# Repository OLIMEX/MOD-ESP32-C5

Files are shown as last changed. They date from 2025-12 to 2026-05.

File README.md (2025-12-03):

# MOD-ESP32-C5
ESP32-C5 dual band 2.4/5Ghz WiFi6 UEXT module

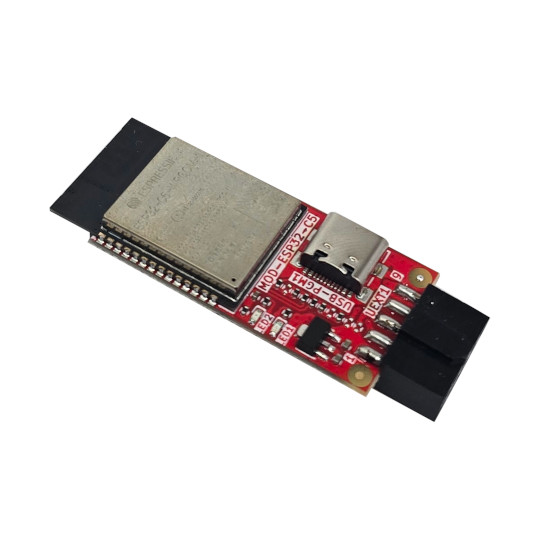
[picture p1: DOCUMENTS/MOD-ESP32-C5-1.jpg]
MOD-ESP32-C5-1


https://www.olimex.com/Products/IoT/ESP32-C5/MOD-ESP32-C5/open-source-hardware

## Licensee
* Hardware is released under CERN Open Hardware Licence Version 2 - Strongly Reciprocal
* Software is released under MIT Licensee
* Documentation is released under CC BY-SA 4.0

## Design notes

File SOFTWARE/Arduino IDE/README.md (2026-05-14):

# MOD-ESP32-C5 Arduino IDE Software

This directory contains the Arduino IDE library, MOD-ESP32-C5 firmware example,
host board demos, and Linux userspace demos for using MOD-ESP32-C5 as a WiFi
modem over UEXT/UART.

## Directory Layout

```text
Arduino IDE/
  README.md
  OlimexWiFiModem.zip
  OlimexWiFiModem/
    library.properties
    README.md
    src/
    examples/
      ESP32_C5_Firmware/
      BasicDemo/
      WebServerDemo/
  Linux/
    README.md
    requirements.txt
    olimex_wifi_modem.py
    basic_demo.py
    web_server_demo.py
```

## Arduino IDE Library

Use `OlimexWiFiModem.zip` for the normal Arduino IDE install flow:

1. Open Arduino IDE.
2. Select `Sketch -> Include Library -> Add .ZIP Library...`.
3. Select `OlimexWiFiModem.zip`.
4. Open examples from `File -> Examples -> OlimexWiFiModem`.

The unzipped `OlimexWiFiModem/` folder is included for source browsing,
development, and GitHub visibility. Its internal structure is the standard
Arduino library layout.

Important examples:

- `ESP32_C5_Firmware` - upload this to MOD-ESP32-C5.
- `BasicDemo` - upload this to an Arduino-compatible host board to test WiFi.
- `WebServerDemo` - upload this to a host board to serve a browser LED button.

Read [OlimexWiFiModem/README.md](OlimexWiFiModem/README.md) for the full
Arduino setup guide.

## Linux Examples

The `Linux/` folder contains Python examples for OLinuXino boards and other
Linux hosts connected to MOD-ESP32-C5 over UEXT/UART.

The MOD-ESP32-C5 must already be flashed with the Arduino
`ESP32_C5_Firmware` example before using the Linux scripts.

Read [Linux/README.md](Linux/README.md) for Linux installation and usage.

## Tested Notes

- OLIMEXINO-2560 host examples use `Serial1` for UEXT.
- A20-OLinuXino-MICRO UEXT1 was tested as `/dev/ttyS4`.
- A20-OLinuXino-MICRO LED1 is controlled through `/sys/class/leds`.
- UART speed is `115200 baud`.

For other boards, adjust the host serial port or Linux `/dev/ttySx` device to
match the board schematic and image.

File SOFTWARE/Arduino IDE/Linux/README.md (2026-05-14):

# OLinuXino Example For MOD-ESP32-C5

Linux userspace examples for using MOD-ESP32-C5 from an OLinuXino board.

The MOD-ESP32-C5 firmware is assumed to be already flashed with the Arduino
`ESP32_C5_Firmware` example. These files only run on the Linux host board.

## Files

```text
Linux/
  README.md
  requirements.txt
  olimex_wifi_modem.py
  basic_demo.py
  web_server_demo.py
```

- `olimex_wifi_modem.py` - Python driver for the MOD-ESP32-C5 UART protocol.
- `basic_demo.py` - checks the modem, connects WiFi, and prints the IP address.
- `web_server_demo.py` - serves a browser button through MOD-ESP32-C5.

## Install Dependency

On Debian-based OLinuXino images:

```sh
apt update
apt install python3 python3-serial
```

## Download Directly On The Board

```sh
mkdir -p MOD-ESP32-C5-Linux
cd MOD-ESP32-C5-Linux

wget -O basic_demo.py https://github.com/OLIMEX/MOD-ESP32-C5/raw/refs/heads/main/SOFTWARE/Arduino%20IDE/Linux/basic_demo.py
wget -O olimex_wifi_modem.py https://github.com/OLIMEX/MOD-ESP32-C5/raw/refs/heads/main/SOFTWARE/Arduino%20IDE/Linux/olimex_wifi_modem.py
wget -O web_server_demo.py https://github.com/OLIMEX/MOD-ESP32-C5/raw/refs/heads/main/SOFTWARE/Arduino%20IDE/Linux/web_server_demo.py
```

## Serial Port

For A20-OLinuXino-MICRO with MOD-ESP32-C5 connected to UEXT1, the schematic
shows A20 UART6 on UEXT1. On the tested Linux image this appears as:

```text
/dev/ttyS4
```

The examples default to `/dev/ttyS4`.

For another OLinuXino board, another UEXT connector, or another Linux image,
change `--port /dev/ttyS4` to the correct `/dev/ttySx`.

Useful checks:

```sh
ls -l /dev/ttyS*
dmesg | grep tty
```

## Basic Demo

```sh
python3 basic_demo.py --port /dev/ttyS4 --ssid WIFI_SSID --password WIFI_PASSWORD
```

Expected output:

```text
================================
MOD-ESP32-C5 Linux Basic Demo
================================
Serial port: /dev/ttyS4
Checking modem...
[TX] ping
[RX] PONG
Modem OK
Connecting to WiFi...
[TX] connect MyRouter MyPassword
[RX] WIFI:CONNECTED
[TX] ip
[RX] IP:192.168.0.198
WiFi connected, IP: 192.168.0.198
```

## Web Server Demo

```sh
python3 web_server_demo.py --port /dev/ttyS4 --ssid WIFI_SSID --password WIFI_PASSWORD
```

Open the printed IP address in a browser on the same network.

Expected result:

- Page title: `OLinuXino + MOD-ESP32-C5`
- Button toggles LED1 on A20-OLinuXino-MICRO.
- Browser refreshes and stale connections are handled without stopping the script.

On A20-OLinuXino-MICRO, LED1 is exposed by the kernel LED subsystem. The web
demo selects a likely LED automatically. To choose one explicitly:

```sh
ls -l /sys/class/leds
python3 web_server_demo.py --port /dev/ttyS4 --ssid WIFI_SSID --password WIFI_PASSWORD --led LED_NAME
```

To run the web demo without controlling a physical LED:

```sh
python3 web_server_demo.py --port /dev/ttyS4 --ssid WIFI_SSID --password WIFI_PASSWORD --no-led
```

## Notes

- Run as `root` if your Linux image restricts serial or LED access.
- If the log shows `DATA:0`, `ERROR:BAD_ID`, or `ERROR:CLOSED` during browser
  refreshes, this usually means the browser opened or closed an extra socket.
  The latest scripts treat this as normal and keep running.
- If the log shows split protocol text such as `S` followed by
  `ERVER:CLIENT:3`, update `olimex_wifi_modem.py`; the driver reassembles known
  fragmented protocol lines.

## Protocol Summary

The Linux scripts send newline-terminated text commands over UEXT UART:

```text
ping
connect <ssid> <password>
ip
server start <port>
server read <client_id>
server write <client_id> <byte_count>
server close <client_id>
```

Common firmware replies:

```text
PONG
WIFI:CONNECTED
IP:192.168.0.198
SERVER:STARTED
SERVER:CLIENT:0
DATA:304
READY
OK
ERROR:...
```

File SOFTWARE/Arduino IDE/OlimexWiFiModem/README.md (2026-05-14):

# OlimexWiFiModem

Arduino IDE library and examples for using MOD-ESP32-C5 as a WiFi modem over
UEXT/UART.

The main target setup is:

- Main board: OLIMEXINO-2560
- WiFi modem board: MOD-ESP32-C5
- Link between boards: UEXT UART at 115200 baud

The firmware can also be used with other host boards that can talk over a UART,
for example other Arduino-compatible boards or OLIMEX Linux boards connected to
UEXT. The host side must send the same text commands described below.

## What Is In This Folder

```text
OlimexWiFiModem/
  library.properties
  README.md
  src/
    OlimexWiFiModem.h
    OlimexWiFiModem.cpp
  examples/
    ESP32_C5_Firmware/
      ESP32_C5_Firmware.ino
    BasicDemo/
      BasicDemo.ino
    WebServerDemo/
      WebServerDemo.ino
```

`ESP32_C5_Firmware` is uploaded to MOD-ESP32-C5.

`BasicDemo` and `WebServerDemo` are uploaded to the host board, for example
OLIMEXINO-2560.

## Install In Arduino IDE From ZIP

This folder is meant to be zipped and installed directly in Arduino IDE.

1. Zip the whole `OlimexWiFiModem` folder.
2. Open Arduino IDE.
3. Select `Sketch -> Include Library -> Add .ZIP Library...`.
4. Select the ZIP file.
5. Open the examples from `File -> Examples -> OlimexWiFiModem`.

After installation, Arduino IDE should show these examples:

- `ESP32_C5_Firmware`
- `BasicDemo`
- `WebServerDemo`

## Hardware Setup

1. Connect MOD-ESP32-C5 to the host board through UEXT.
2. Power the boards as recommended for your hardware.
3. Use a USB cable for the board you are programming.
4. Open Serial Monitor at `115200 baud`.

For OLIMEXINO-2560, the examples use:

```cpp
HardwareSerial &ModemSerial = Serial1;
```

This means the library talks to MOD-ESP32-C5 through `Serial1`.

For another host board, change this line to the hardware serial port connected
to the UEXT UART.

## Step 1: Upload The MOD-ESP32-C5 Firmware

Open:

`File -> Examples -> OlimexWiFiModem -> ESP32_C5_Firmware`

Select the correct ESP32-C5 board and port in Arduino IDE, then upload.

After reset, open Serial Monitor at `115200 baud`. Expected output:

```text
READY
>
```

This means the firmware is running and waiting for commands from the host board.

## Step 2: Run BasicDemo On The Host Board

Open:

`File -> Examples -> OlimexWiFiModem -> BasicDemo`

Before uploading, edit these two lines:

```cpp
#define WIFI_SSID "WIFI_SSID"
#define WIFI_PASSWORD "WIFI_PASSWORD"
```

Example:

```cpp
#define WIFI_SSID "MyRouter"
#define WIFI_PASSWORD "MyPassword"
```

Upload the sketch to OLIMEXINO-2560 or another host board.

Open Serial Monitor at `115200 baud`. Expected output will look similar to:

```text
================================
OlimexWiFiModem Basic Demo
================================
Checking MOD-ESP32-C5...
[TX] ping
[RX] PONG
Modem OK
Connecting to WiFi...
[TX] connect MyRouter MyPassword
[RX] WIFI:CONNECTED
WiFi connected
[TX] ip
[RX] IP:192.168.0.198
IP: 192.168.0.198
Basic demo finished.
```

Your IP address will probably be different.

## Step 3: Run WebServerDemo On The Host Board

Open:

`File -> Examples -> OlimexWiFiModem -> WebServerDemo`

Before uploading, edit these two lines:

```cpp
#define WIFI_SSID "WIFI_SSID"
#define WIFI_PASSWORD "WIFI_PASSWORD"
```

Upload the sketch and open Serial Monitor at `115200 baud`.

Expected startup output:

```text
================================
OLIMEXINO-2560 Web Server Demo
================================
[TX] ping
[RX] PONG
Modem OK
Connecting to WiFi...
[TX] connect MyRouter MyPassword
[RX] WIFI:CONNECTED
WiFi connected
[TX] ip
[RX] IP:192.168.0.198
Module IP: 192.168.0.198
[TX] server start 80
[RX] SERVER:STARTED
HTTP server started
Open browser: http://192.168.0.198
```

Open the printed address in a browser connected to the same network.

Expected result:

- A web page opens with title `OLIMEXINO-2560`.
- The page shows `LED is OFF` or `LED is ON`.
- Pressing `Toggle LED` changes the board LED on pin 13.
- The page updates quickly without a full page reload.

When the browser connects, Serial Monitor will show request/response activity:

```text
[RX] SERVER:CLIENT:0
Client connected, ID=0
[TX] server read 0
[RX] DATA:304
Request: GET /toggle HTTP/1.1
LED state changed to: ON
[TX] server write 0 91
[RX] READY
[RX] OK
[TX] server close 0
[RX] OK
Client closed
```

The exact byte counts can be different.

## How The Firmware And Library Communicate

The host board sends text commands to MOD-ESP32-C5 over UART. Each command ends
with a newline.

Common commands:

```text
ping
connect <ssid> <password>
ip
server start <port>
server read <client_id>
server write <client_id> <byte_count>
server close <client_id>
```

Common firmware replies:

```text
PONG
WIFI:CONNECTED
IP:192.168.0.198
SERVER:STARTED
SERVER:CLIENT:0
DATA:304
READY
OK
ERROR:...
```

For HTTP server use, MOD-ESP32-C5 accepts the browser connection and notifies
the host board with `SERVER:CLIENT:<id>`. The host board then reads the browser
request, writes an HTTP response, and closes the browser client.

## Troubleshooting

If Serial Monitor shows `Modem not found`:

- Check that MOD-ESP32-C5 is flashed with `ESP32_C5_Firmware`.
- Check UEXT connection and board power.
- Check that the host sketch uses the correct serial port.
- Make sure both sides use `115200 baud`.

If Serial Monitor shows `WiFi failed`:

- Check the SSID and password.
- Make sure the WiFi network is in range.
- Use a 2.4 GHz network if your ESP32-C5 setup does not support the selected
  router mode.

If the web page does not open:

- Confirm that `HTTP server started` is printed.
- Confirm that your computer or phone is on the same network.
- Open the exact IP address printed by the Serial Monitor.
- Try refreshing the browser after the board prints a new IP address.

If the button is slow or stops responding:

- Reflash MOD-ESP32-C5 with the firmware from this library.
- Reupload the latest `WebServerDemo`.
- Watch Serial Monitor for `ERROR:` messages.

## Using Other Host Boards

The library is written for Arduino-style `Stream` objects. This means the host
board only needs a serial port connected to the MOD-ESP32-C5 UEXT UART.

For boards such as OLIMEXINO-328, the serial port may be different from
OLIMEXINO-2560. Update this line in the demos:

```cpp
HardwareSerial &ModemSerial = Serial1;
```

Use the serial object that matches your wiring.

For Linux boards, the same protocol can be used from a userspace program that
opens the UEXT serial device at `115200 baud` and sends the text commands shown
above.

## Notes For Beginners

- Upload `ESP32_C5_Firmware` to MOD-ESP32-C5 first.
- Upload `BasicDemo` or `WebServerDemo` to the main board second.
- Always edit `WIFI_SSID` and `WIFI_PASSWORD` before uploading host demos.
- Keep Serial Monitor open at `115200 baud`; it is the easiest way to see what
  is happening.
- The IP address is assigned by your router, so it may change between tests.

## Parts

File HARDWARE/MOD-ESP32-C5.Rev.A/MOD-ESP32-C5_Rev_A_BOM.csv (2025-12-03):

Quantity | Value | Footprint | Reference
1 | 1uF/6.3V/10%/X5R/C0402 | C_0402_5MIL_DWS | C3
2 | 10uF/6.3V/20%/X5R/C0402 | C_0402_5MIL_DWS | C6, C7
1 | LED/Green/0603 | LED_0603_KA | LED1
1 | LED/Red/0603 | LED_0603_KA | LED2
2 | 5.1k/1%/R0402 | R_0402_5MIL_DWS | R1, R2
1 | 10k/R0402 | R_0402_5MIL_DWS | R3
2 | 33R/R0402 | R_0402_5MIL_DWS | R4, R5
2 | 2.2k/R0402 | R_0402_5MIL_DWS | R6, R7
2 | GG0402052R542P | D_0402_5MIL_DWS | TVS1, TVS2
1 | ESP32-C5-WROOM-1-N8R4 | ESP32-C5-WROOM-1-N**4-UNIVERSAL_MODULE | U1
1 | FK-DK-2X05-LF(IDC-10S_PCB) | FK-DK-2X05-LF(IDC-10S_PCB)-SMD | UEXT1
1 | USB-C-16P-F(A40-00119-A52-12) | USB2.0_TYPE-C(A40-00119-A52-12)_Paste | USB-PGM1
1 | WL9005P3-33(SOT89-3) | SOT89-3 | VR1

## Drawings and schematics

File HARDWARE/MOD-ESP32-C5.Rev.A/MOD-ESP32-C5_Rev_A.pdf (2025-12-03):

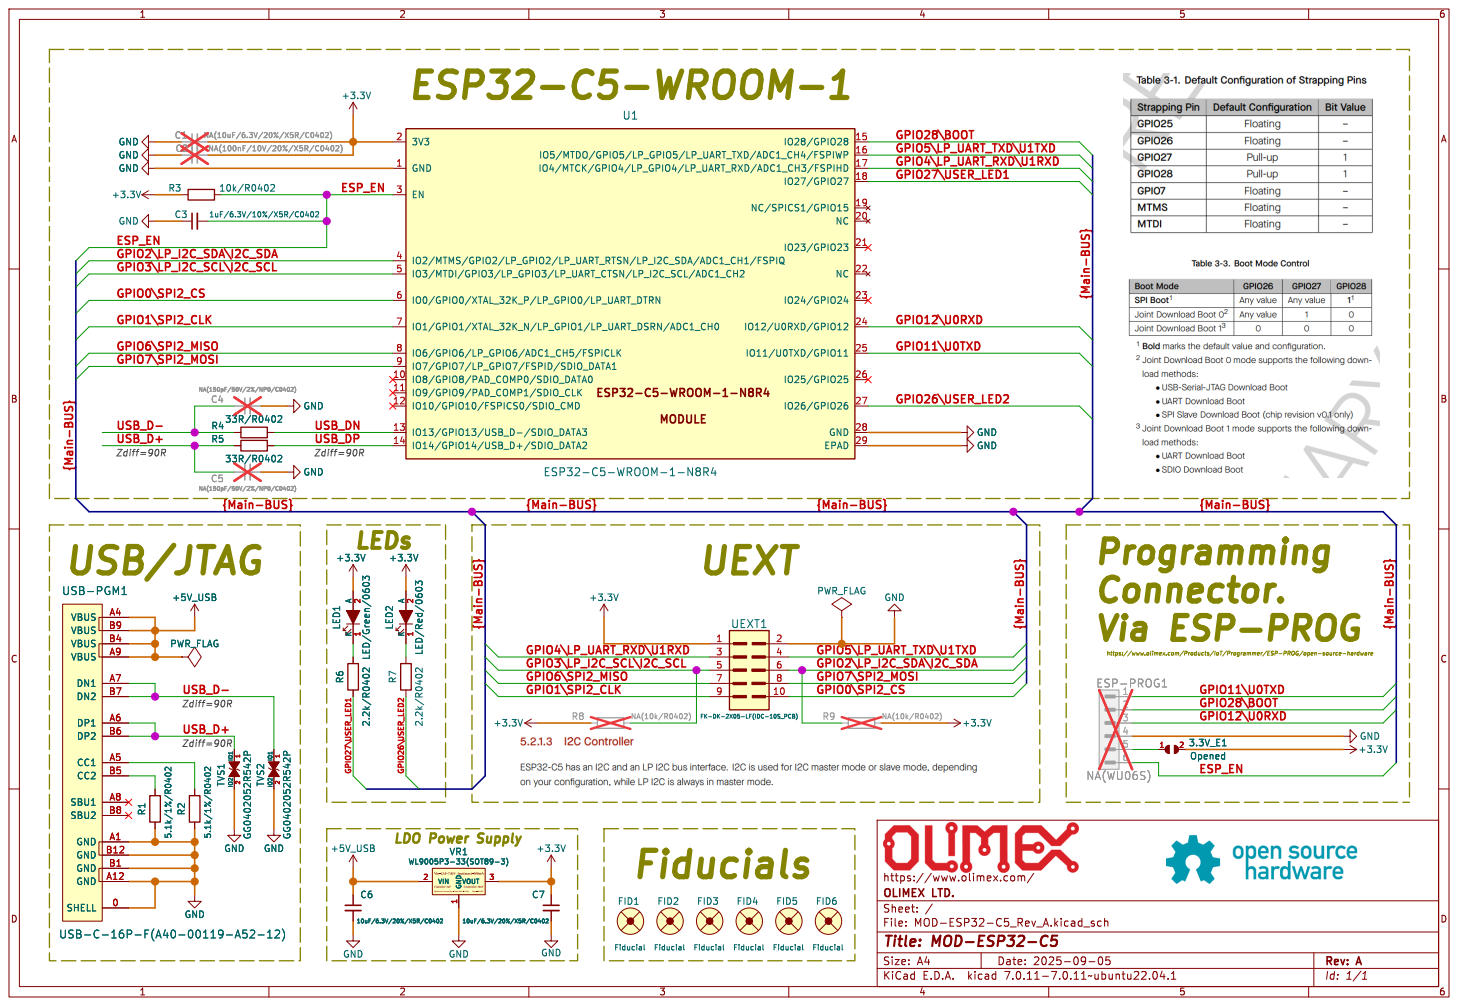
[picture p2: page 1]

Via ESP-PROG https://www.olimex.com/Products/IoT/Programmer/ESP-PROG/open-source-hardware Fiducials

FK-DK-2X05-LF(IDC-10S_PCB)

QuiescentCurrent(Typ=0.3uA;Max=0.7uA) Topr=-40~85C Vin=(2.0~7.0)V GND

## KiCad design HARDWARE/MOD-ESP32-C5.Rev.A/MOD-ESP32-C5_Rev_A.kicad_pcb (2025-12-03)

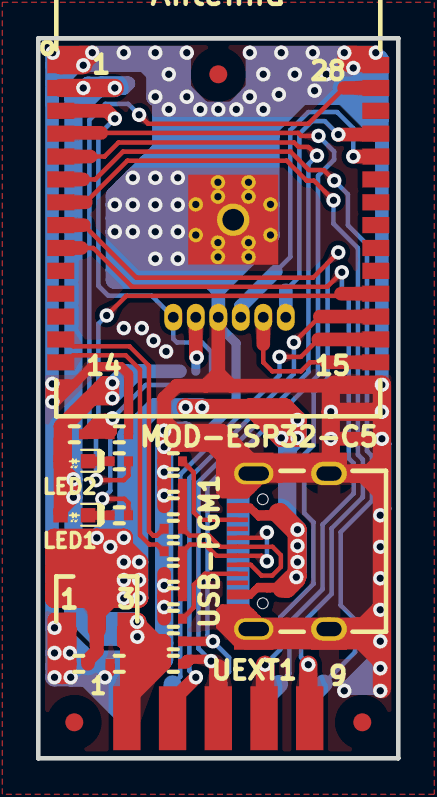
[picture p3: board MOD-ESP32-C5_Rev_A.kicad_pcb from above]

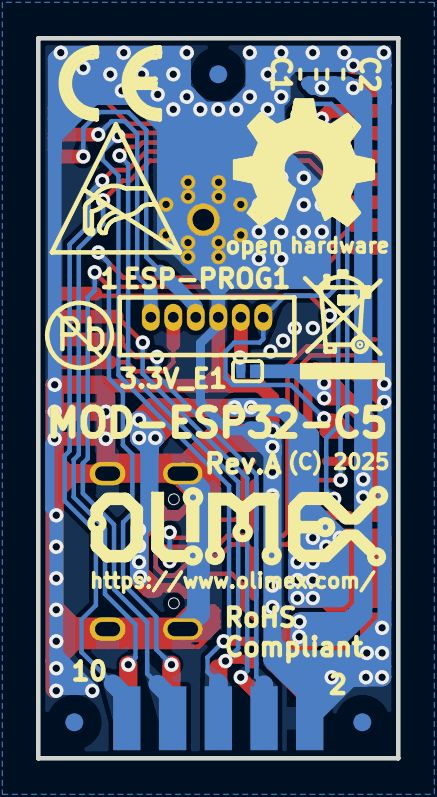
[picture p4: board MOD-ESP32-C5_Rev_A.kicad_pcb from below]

Board: 2 copper layers, 20.0 x 40.0 mm, 38 parts (13 on the bottom side), 26 nets.

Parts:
3.3V_E1: Opened; SJ_1_SMALLER
C1: NA(10uF/6.3V/20%/X5R/C0402); C_0402_5MIL_DWS
C2: NA(100nF/10V/20%/X5R/C0402); C_0402_5MIL_DWS
C3: 1uF/6.3V/10%/X5R/C0402; C_0402_5MIL_DWS
C4, C5: NA(150pF/50V/2%/NP0/C0402); C_0402_5MIL_DWS
C6, C7: 10uF/6.3V/20%/X5R/C0402; C_0402_5MIL_DWS
ESP-PROG1: NA(WU06S); WU06S
FID1, FID2, FID5, FID6: Fiducial; Fiducial1x3
FID3, FID4: Fiducial; Fiducial1x3_Paste
LED1: LED/Green/0603; LED_0603_KA
LED2: LED/Red/0603; LED_0603_KA
Logo_OLIMEX_TB: Logo_OLIMEX_TB
R1, R2: 5.1k/1%/R0402; R_0402_5MIL_DWS
R3: 10k/R0402; R_0402_5MIL_DWS
R4, R5: 33R/R0402; R_0402_5MIL_DWS
R6, R7: 2.2k/R0402; R_0402_5MIL_DWS
R8, R9: NA(10k/R0402); R_0402_5MIL_DWS
Sign_Antistatic: Sign_Antistatic
Sign_CE: CE_Sign
Sign_OSHW_8x8: Sign_OSHW_8x8
Sign_PB-Free: Sign_PB-Free
Sign_RecycleBin_1: Sign_RecycleBin_1
TVS1, TVS2: GG0402052R542P; D_0402_5MIL_DWS
U1: ESP32-C5-WROOM-1-N8R4; ESP32-C5-WROOM-1-N**4-UNIVERSAL_MODULE
UEXT1: FK-DK-2X05-LF(IDC-10S_PCB); FK-DK-2X05-LF(IDC-10S_PCB)-SMD
USB-PGM1: USB-C-16P-F(A40-00119-A52-12); USB2.0_TYPE-C(A40-00119-A52-12)_Paste
VR1: WL9005P3-33(SOT89-3); SOT89-3

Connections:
+3.3V: 3.3V_E1.2, C1.2, C2.1, C7.1, LED1.2 (A), LED2.2 (A), R3.2, R8.1, R9.2, U1.2 (3V3), UEXT1.1, VR1.3 (VOUT)
+5V_USB: C6.1, USB-PGM1.A4 (VBUS), USB-PGM1.A9 (VBUS), USB-PGM1.B4 (VBUS), USB-PGM1.B9 (VBUS), VR1.2 (VIN)
/ESP_EN: C3.2, ESP-PROG1.6, R3.1, U1.3 (EN)
/GPIO0\SPI2_CS: U1.6 (IO0/GPIO0/XTAL_32K_P/LP_GPIO0/LP_UART_D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), UEXT1.10
/GPIO1\SPI2_CLK: U1.7 (IO1/GPIO1/XTAL_32K_N/LP_GPIO1/LP_UART_D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), UEXT1.9
/GPIO2\LP_I2C_SDA\I2C_SDA: R9.1, U1.4 (IO2/MTMS/GPIO2/LP_GPIO2/LP_UART_RTSN/LP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), UEXT1.6
/GPIO3\LP_I2C_SCL\I2C_SCL: R8.2, U1.5 (IO3/MTDI/GPIO3/LP_GPIO3/LP_UART_CTSN/LP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), UEXT1.5
/GPIO4\LP_UART_RXD\U1RXD: U1.17 (IO4/MTCK/GPIO4/LP_GPIO4/LP_UART_RXD/ADC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), UEXT1.3
/GPIO5\LP_UART_TXD\U1TXD: U1.16 (IO5/MTDO/GPIO5/LP_GPIO5/LP_UART_TXD/ADC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), UEXT1.4
/GPIO6\SPI2_MISO: U1.8 (IO6/GPIO6/LP_GPIO6/ADC1_CH5/FSPICLK), UEXT1.7
/GPIO7\SPI2_MOSI: U1.9 (IO7/GPIO7/LP_GPIO7/FSPID/SDIO_DATA1), UEXT1.8
/GPIO11\U0TXD: ESP-PROG1.1, U1.25 (IO11/U0TXD/GPIO11)
/GPIO12\U0RXD: ESP-PROG1.3, U1.24 (IO12/U0RXD/GPIO12)
/GPIO26\USER_LED2: R7.2, U1.27 (IO26/GPIO26)
/GPIO27\USER_LED1: R6.2, U1.18 (IO27/GPIO27)
/GPIO28\BOOT: ESP-PROG1.2, U1.15 (IO28/GPIO28)
/USB_D+: C5.1, R5.2, TVS1.1 (IO1), USB-PGM1.A6 (DP1), USB-PGM1.B6 (DP2)
/USB_D-: C4.1, R4.1, TVS2.1 (IO1), USB-PGM1.A7 (DN1), USB-PGM1.B7 (DN2)
/USB_DN: R4.2, U1.13 (IO13/GPIO13/USB_D-/SDIO_DATA3)
/USB_DP: R5.1, U1.14 (IO14/GPIO14/USB_D+/SDIO_DATA2)
GND: C1.1, C2.2, C3.1, C4.2, C5.2, C6.2, C7.2, ESP-PROG1.4, R1.1, R2.1, TVS1.2 (IO2), TVS2.2 (IO2), U1.1 (GND), U1.28 (GND), U1.29 (EPAD), UEXT1.2, USB-PGM1.0 (SHELL), USB-PGM1.A1 (GND), USB-PGM1.A12 (GND), USB-PGM1.B1 (GND), USB-PGM1.B12 (GND), VR1.1 (GND)
unnamed: 3.3V_E1.1, ESP-PROG1.5
unnamed: LED1.1 (K), R6.1
unnamed: LED2.1 (K), R7.1
unnamed: R2.2, USB-PGM1.A5 (CC1)
unnamed: R1.2, USB-PGM1.B5 (CC2)

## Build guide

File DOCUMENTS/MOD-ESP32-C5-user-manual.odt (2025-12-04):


MOD-ESP32-C5

User Manual

Rev.1.0 November 2025 olimex.com

# What is MOD-ESP32-C5

MOD- (https://www.olimex.com/Products/IoT/ESP32-C5/MOD-ESP32-C5/open-source-hardware)ESP32-C5 (https://www.olimex.com/Products/IoT/ESP32-C5/MOD-ESP32-C5/open-source-hardware) is Dual band 2.4Ghz and 5Ghz WiFi 6, Bluetooth 5 LE, Zigbee, Thread, Matter development board with UEXTconnector.

The board is with ESP32-C5-WROOM-N8R4 module with 8MB of Flash and 4MB of RAM

The features of MOD- (https://www.olimex.com/Products/IoT/ESP32-C5/MOD-ESP32-C5/open-source-hardware)ESP32-C5 (https://www.olimex.com/Products/IoT/ESP32-C5/MOD-ESP32-C5/open-source-hardware) are:

- ESP32-C5-WROOM-N8R4 module
- 32 bit RISC-V processor 240Mhz
- Dual-Band Wi-Fi (2.4 GHz + 5 GHz)
- Bluetooth 5, Zigbee, Thread, Matter
- 8 MB Flash + 4 MB RAM
- UEXT connector
- USB-C JTAG
- Two status LEDs
- Dimensions 40x20mm
  MOD- (https://www.olimex.com/Products/IoT/ESP32-C5/MOD-ESP32-C5/open-source-hardware)ESP32-C5 (https://www.olimex.com/Products/IoT/ESP32-C5/MOD-ESP32-C5/open-source-hardware) is Open Source Hardware, all CAD files and firmware and available, so people can study and modify.

## Order codes for MOD-ESP32-C5 and accessories:

MOD- (https://www.olimex.com/Products/IoT/ESP32-C5/MOD-ESP32-C5/open-source-hardware)ESP32-C5 (https://www.olimex.com/Products/IoT/ESP32-C5/MOD-ESP32-C5/open-source-hardware) ESP32-C5 development board

USB-CABLE-AM-USB3-C (https://www.olimex.com/Products/Components/Cables/USB-CABLE-AM-USB3-C/) High speed, High current cable for power supply and programming

# HARDWARE

## MOD-ESP32-C5 layout:

## UEXT connector:

MOD- (https://www.olimex.com/Products/IoT/ESP32-C5/MOD-ESP32-C5/open-source-hardware)ESP32-C5 (https://www.olimex.com/Products/IoT/ESP32-C5/MOD-ESP32-C5/open-source-hardware) has UEXT connector which is compatible with the UEXT connector on all our other development boards.

Note that UEXT connector have UART which signals have to be crossed. So there is UEXT HOST and UEXT device connectors.

The UEXT HOST connector is male connector with pins. The UEXT DEVICE connector is with receptacle connector.

Our development boards with UEXT have UEXT HOST connector.

MOD- (https://www.olimex.com/Products/IoT/ESP32-C5/MOD-ESP32-C5/open-source-hardware)ESP32-C5 (https://www.olimex.com/Products/IoT/ESP32-C5/MOD-ESP32-C5/open-source-hardware) is with UEXT DEVICE connector.

UEXT connector can be in different shapes.

The original UEXT connector is 0.1” 2.54mm step boxed plastic connector. All signals are with 3.3V levels. Here is picture of UEXT HOST connector (with pins):

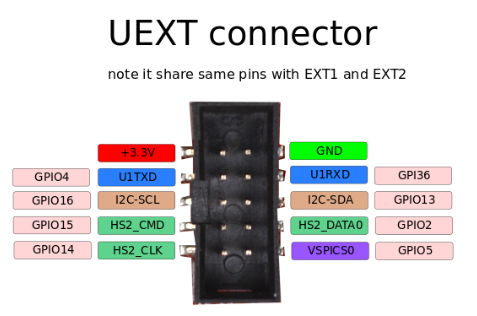
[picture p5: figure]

## MOD-ESP32-C5 UEXT connector wiring:

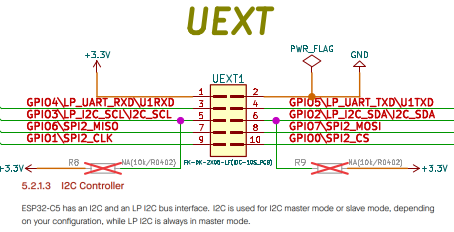
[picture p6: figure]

## LEDs:

MOD- (https://www.olimex.com/Products/IoT/ESP32-C5/MOD-ESP32-C5/open-source-hardware)ESP32-C5 (https://www.olimex.com/Products/IoT/ESP32-C5/MOD-ESP32-C5/open-source-hardware) has two status LEDs

LED1 is Green and connected to GPIO27

LED2 is Red and connected to GPIO26

## MOD-ESP32-C5 schematics:

MOD- (https://www.olimex.com/Products/IoT/ESP32-C5/MOD-ESP32-C5/open-source-hardware)ESP32-C5 (https://www.olimex.com/Products/IoT/ESP32-C5/MOD-ESP32-C5/open-source-hardware) latest schematic is on GitHub (https://github.com/OLIMEX/MOD-ESP32-C5/blob/main/HARDWARE/MOD-ESP32-C5.Rev.A/MOD-ESP32-C5_Rev_A.pdf)

# SOFTWARE:

ESP32-C5- (https://www.olimex.com/Products/IoT/ESP32-C5/ESP32-C5-DevKit-Lipo/open-source-hardware)DevKit-Lipo (https://www.olimex.com/Products/IoT/ESP32-C5/ESP32-C5-DevKit-Lipo/open-source-hardware) can be programmed with Espressif IDF 5.5 and Arduino.

# Revision History

Revision 1.0 November 2025

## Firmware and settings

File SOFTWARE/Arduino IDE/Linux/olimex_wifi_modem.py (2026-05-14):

#!/usr/bin/env python3
"""Linux driver for MOD-ESP32-C5 running the Olimex WiFi modem firmware."""

import time

import serial


class OlimexWiFiModem:
    def __init__(self, port="/dev/ttyS4", baudrate=115200, debug=True):
        self.ser = serial.Serial(port=port, baudrate=baudrate, timeout=0.05)
        self.debug = debug
        self.pending_clients = []
        self.line_fragment = ""

    def close(self):
        self.ser.close()

    def flush_input(self):
        self.ser.reset_input_buffer()

    def send_cmd(self, cmd):
        if self.debug:
            print(f"[TX] {cmd}")
        self.ser.write((cmd + "\n").encode("utf-8"))
        self.ser.flush()

    def normalize_line(self, line):
        known = (
            "PONG",
            "WIFI:CONNECTED",
            "IP:",
            "SERVER:STARTED",
            "SERVER:CLIENT:",
            "DATA:",
            "READY",
            "OK",
            "END",
            "ERROR:",
        )

        if self.line_fragment:
            line = self.line_fragment + line
            self.line_fragment = ""

        if line in ("WIFI:", "IP:", "DATA:", "SERVER:CLIENT:", "ERROR:"):
            self.line_fragment = line
            return ""

        if any(prefix.startswith(line) and prefix != line for prefix in known):
            self.line_fragment = line
            return ""

        return line

    def read_line(self, timeout=2.0):
        end = time.monotonic() + timeout
        data = bytearray()

        while time.monotonic() < end:
            b = self.ser.read(1)
            if not b:
                continue

            ch = b[0]
            if ch == ord("\r"):
                continue

            if ch == ord("\n"):
                line = data.decode("utf-8", errors="replace").strip()
                if line.startswith(">"):
                    line = line[1:].strip()
                if line:
                    return self.normalize_line(line)
                data.clear()
                continue

            if ch == ord(">") and not data:
                continue

            data.append(ch)

        line = data.decode("utf-8", errors="replace").strip()
        if line.startswith(">"):
            line = line[1:].strip()
        if line:
            return self.normalize_line(line)
        return line

    def read_exact(self, size, timeout=2.0):
        end = time.monotonic() + timeout
        data = bytearray()

        while len(data) < size and time.monotonic() < end:
            chunk = self.ser.read(size - len(data))
            if chunk:
                data.extend(chunk)

        if len(data) != size:
            raise TimeoutError(f"Expected {size} bytes, received {len(data)}")

        return bytes(data)

    def cache_client_line(self, line):
        if line.startswith("SERVER:CLIENT:"):
            self.pending_clients.append(int(line.split(":", 2)[2]))
            return True
        return False

    def wait_for(self, token, timeout=3.0):
        end = time.monotonic() + timeout
        recent = ""

        while time.monotonic() < end:
            line = self.read_line(timeout=0.2)
            if not line:
                continue

            if self.debug:
                print(f"[RX] {line}")

            self.cache_client_line(line)

            if line.startswith("ERROR:"):
                return False

            recent = (recent + line)[-128:]

            if token in line or token in recent:
                return True

        return False

    def begin(self):
        self.flush_input()
        self.send_cmd("ping")
        return self.wait_for("PONG", timeout=3.0)

    def connect_wifi(self, ssid, password):
        self.flush_input()
        self.send_cmd(f"connect {ssid} {password}")
        return self.wait_for("WIFI:CONNECTED", timeout=15.0)

    def ip(self):
        self.flush_input()
        self.send_cmd("ip")

        end = time.monotonic() + 3.0
        while time.monotonic() < end:
            line = self.read_line(timeout=0.5)
            if not line:
                continue

            if self.debug:
                print(f"[RX] {line}")

            self.cache_client_line(line)

            if line.startswith("IP:"):
                return line[3:]

        return ""

    def server_start(self, port=80):
        self.flush_input()
        self.send_cmd(f"server start {port}")
        return self.wait_for("SERVER:STARTED", timeout=3.0)

    def server_available(self):
        if self.pending_clients:
            return self.pending_clients.pop(0)

        line = self.read_line(timeout=0.05)
        if not line:
            return -1

        if self.debug:
            print(f"[RX] {line}")

        if line.startswith("SERVER:CLIENT:"):
            return int(line.split(":", 2)[2])

        return -1

    def server_read(self, client_id, timeout=2.0):
        self.send_cmd(f"server read {client_id}")
        end = time.monotonic() + timeout

        while time.monotonic() < end:
            line = self.read_line(timeout=0.2)
            if not line:
                continue

            if self.debug:
                print(f"[RX] {line}")

            if line in ("ERROR:BAD_ID", "ERROR:CLOSED"):
                return None

            if line.startswith("ERROR:"):
                raise RuntimeError(line)

            if self.cache_client_line(line):
                continue

            if not line.startswith("DATA:"):
                continue

            size = int(line[5:])
            payload = self.read_exact(size, timeout=timeout)

            trailer_end = time.monotonic() + 0.5
            while time.monotonic() < trailer_end:
                trailer = self.read_line(timeout=0.1)
                if trailer == "END":
                    break
                if trailer:
                    if self.debug:
                        print(f"[RX] {trailer}")
                    self.cache_client_line(trailer)

            return payload

        raise TimeoutError("Timed out waiting for DATA")

    def server_write(self, client_id, data):
        if isinstance(data, str):
            data = data.encode("utf-8")

        self.send_cmd(f"server write {client_id} {len(data)}")

        if not self.wait_for("READY", timeout=3.0):
            return False

        self.ser.write(data)
        self.ser.flush()

        return self.wait_for("OK", timeout=3.0)

    def server_close(self, client_id):
        self.send_cmd(f"server close {client_id}")
        return self.wait_for("OK", timeout=3.0)

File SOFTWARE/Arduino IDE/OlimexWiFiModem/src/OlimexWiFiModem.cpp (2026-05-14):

#include "OlimexWiFiModem.h"

OlimexWiFiModem::OlimexWiFiModem(
  Stream &serial,
  Stream *debug
)
: _serial(serial),
  _debug(debug),
  _pendingClientCount(0) {
}

bool OlimexWiFiModem::begin(uint32_t timeout) {

  flushInput();

  sendCmd("ping");

  return waitFor("PONG", timeout);
}

void OlimexWiFiModem::flushInput() {

  while (_serial.available()) {
    _serial.read();
  }
}

void OlimexWiFiModem::sendCmd(const String &cmd) {

  if (_debug) {
    _debug->print("[TX] ");
    _debug->println(cmd);
  }

  _serial.print(cmd);
  _serial.print('\n');
}

void OlimexWiFiModem::cacheClient(int id) {

  if (id < 0) {
    return;
  }

  if (_pendingClientCount >= 8) {
    return;
  }

  _pendingClients[_pendingClientCount++] = id;
}

bool OlimexWiFiModem::cacheClientLine(const String &line) {

  if (!line.startsWith("SERVER:CLIENT:")) {
    return false;
  }

  cacheClient(line.substring(14).toInt());

  return true;
}

bool OlimexWiFiModem::waitFor(
  const String &token,
  uint32_t timeout
) {

  uint32_t start = millis();

  while (millis() - start < timeout) {

    String line = readLine(100);

    if (line.length()) {

      if (_debug) {
        _debug->print("[RX] ");
        _debug->println(line);
      }

      cacheClientLine(line);

      if (line.indexOf(token) >= 0) {
        return true;
      }
    }
  }

  return false;
}

String OlimexWiFiModem::readLine(uint32_t timeout) {

  String s;

  uint32_t start = millis();

  while (millis() - start < timeout) {

    while (_serial.available()) {

      char c = _serial.read();

      if (c == '\r')
        continue;

      if (c == '\n') {

        s.trim();

        if (s.length()) {

          return s;
        }

        s = "";

      } else {

        // ignore prompt chars
        if (c == '>') {

          if (s.length() == 0)
            continue;
        }

        s += c;
      }

      start = millis();
    }
  }

  s.trim();

  return s;
}

size_t OlimexWiFiModem::readBytes(
  uint8_t *buffer,
  size_t len,
  uint32_t timeout
) {

  size_t pos = 0;

  uint32_t start = millis();

  while (pos < len && millis() - start < timeout) {

    while (_serial.available() && pos < len) {

      buffer[pos++] = _serial.read();

      start = millis();
    }
  }

  return pos;
}

bool OlimexWiFiModem::connect(
  const String &ssid,
  const String &pass
) {

  flushInput();

  sendCmd("connect " + ssid + " " + pass);

  return waitFor("WIFI:CONNECTED", 15000);
}

bool OlimexWiFiModem::disconnect() {

  flushInput();

  sendCmd("disconnect");

  return waitFor("OK", 3000);
}

bool OlimexWiFiModem::isConnected() {

  flushInput();

  sendCmd("status");

  return waitFor("WIFI:CONNECTED", 3000);
}

String OlimexWiFiModem::ip() {

  flushInput();

  sendCmd("ip");

  uint32_t start = millis();

  while (millis() - start < 3000) {

    String line = readLine(3000);

    line.trim();

    if (_debug && line.length()) {
      _debug->print("[RX] ");
      _debug->println(line);
    }

    // remove prompt contamination
    if (line.startsWith(">")) {

      line.remove(0, 1);

      line.trim();
    }

    if (line.startsWith("IP:")) {

      return line.substring(3);
    }
  }

  return "";
}

bool OlimexWiFiModem::serverStart(uint16_t port) {

  flushInput();

  sendCmd("server start " + String(port));

  return waitFor("SERVER:STARTED", 3000);
}

int OlimexWiFiModem::serverAvailable() {

  if (_pendingClientCount > 0) {

    int id = _pendingClients[0];

    for (uint8_t i = 1; i < _pendingClientCount; i++) {
      _pendingClients[i - 1] = _pendingClients[i];
    }

    _pendingClientCount--;

    return id;
  }

  String line = readLine(10);

  if (line.startsWith("SERVER:CLIENT:")) {

    if (_debug) {
      _debug->print("[RX] ");
      _debug->println(line);
    }

    return line.substring(14).toInt();
  }

  return -1;
}

int OlimexWiFiModem::serverRead(
  int id,
  uint8_t *buffer,
  size_t maxLen,
  uint32_t timeout
) {

  sendCmd("server read " + String(id));

  uint32_t start = millis();

  while (millis() - start < timeout) {

    String line = readLine(100);

    if (!line.length()) {
      continue;
    }

    if (_debug) {
      _debug->print("[RX] ");
      _debug->println(line);
    }

    if (line.startsWith("ERROR:")) {
      return -1;
    }

    if (cacheClientLine(line)) {
      continue;
    }

    if (!line.startsWith("DATA:")) {
      continue;
    }

    size_t dataLen = line.substring(5).toInt();
    size_t copyLen = dataLen;

    if (copyLen > maxLen) {
      copyLen = maxLen;
    }

    size_t copied = readBytes(buffer, copyLen, timeout);

    if (copied != copyLen) {
      return -1;
    }

    uint8_t discard;

    for (size_t i = copyLen; i < dataLen; i++) {

      if (readBytes(&discard, 1, timeout) != 1) {
        return -1;
      }
    }

    waitFor("END", 500);

    return copyLen;
  }

  return -1;
}

bool OlimexWiFiModem::serverWrite(
  int id,
  const uint8_t *data,
  size_t len
) {

  sendCmd(
    "server write " +
    String(id) +
    " " +
    String(len)
  );

  if (!waitFor("READY", 3000)) {
    return false;
  }

  _serial.write(data, len);

  return waitFor("OK", 3000);
}

bool OlimexWiFiModem::serverWrite(
  int id,
  const String &s
) {

  return serverWrite(
    id,
    (const uint8_t*)s.c_str(),
    s.length()
  );
}

bool OlimexWiFiModem::serverClose(int id) {

  sendCmd("server close " + String(id));

  return waitFor("OK", 3000);
}

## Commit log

2025-12-03 initial upload
    [MOD-ESP32-C5_Rev_A-B_Cu.gbr, MOD-ESP32-C5_Rev_A-B_Mask.gbr, MOD-ESP32-C5_Rev_A-B_Paste.gbr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]
2026-05-14 Update
    Added WIFI functionality firmware and demos with Olimexino-2560 for Arduino IDE
2026-05-14 Update
    Py scripts for Olinuxino boards

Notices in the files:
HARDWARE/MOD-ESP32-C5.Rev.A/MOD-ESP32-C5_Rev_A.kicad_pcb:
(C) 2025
